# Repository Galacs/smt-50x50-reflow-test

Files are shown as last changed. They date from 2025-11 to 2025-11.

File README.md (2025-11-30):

# SMT 50x50 reflow test

ESP32-C6 50x50 board made to test smd reflow techniques with various components packages (QFN, HTSOP, WSON, USBC, SOT, SOIC, 0201)

## IC List

- ESP32-C6 (Main MCU)
- W25Q128JVSIQ (16MB program storage spi flash)
- 2x TMP117 (I2C temperature sensor)
- BMP581 (I2C/SPI pressure sensor)
- LMR36520 (wide Vin buck converter)
- LM317A (high Vin LDO)
- AP2112K (MCU LDO)
- 2450AT18A100E (2.45GHz Ceramic chip antenna)
- 01005 resistors

## Top preview



## Preview 3d render



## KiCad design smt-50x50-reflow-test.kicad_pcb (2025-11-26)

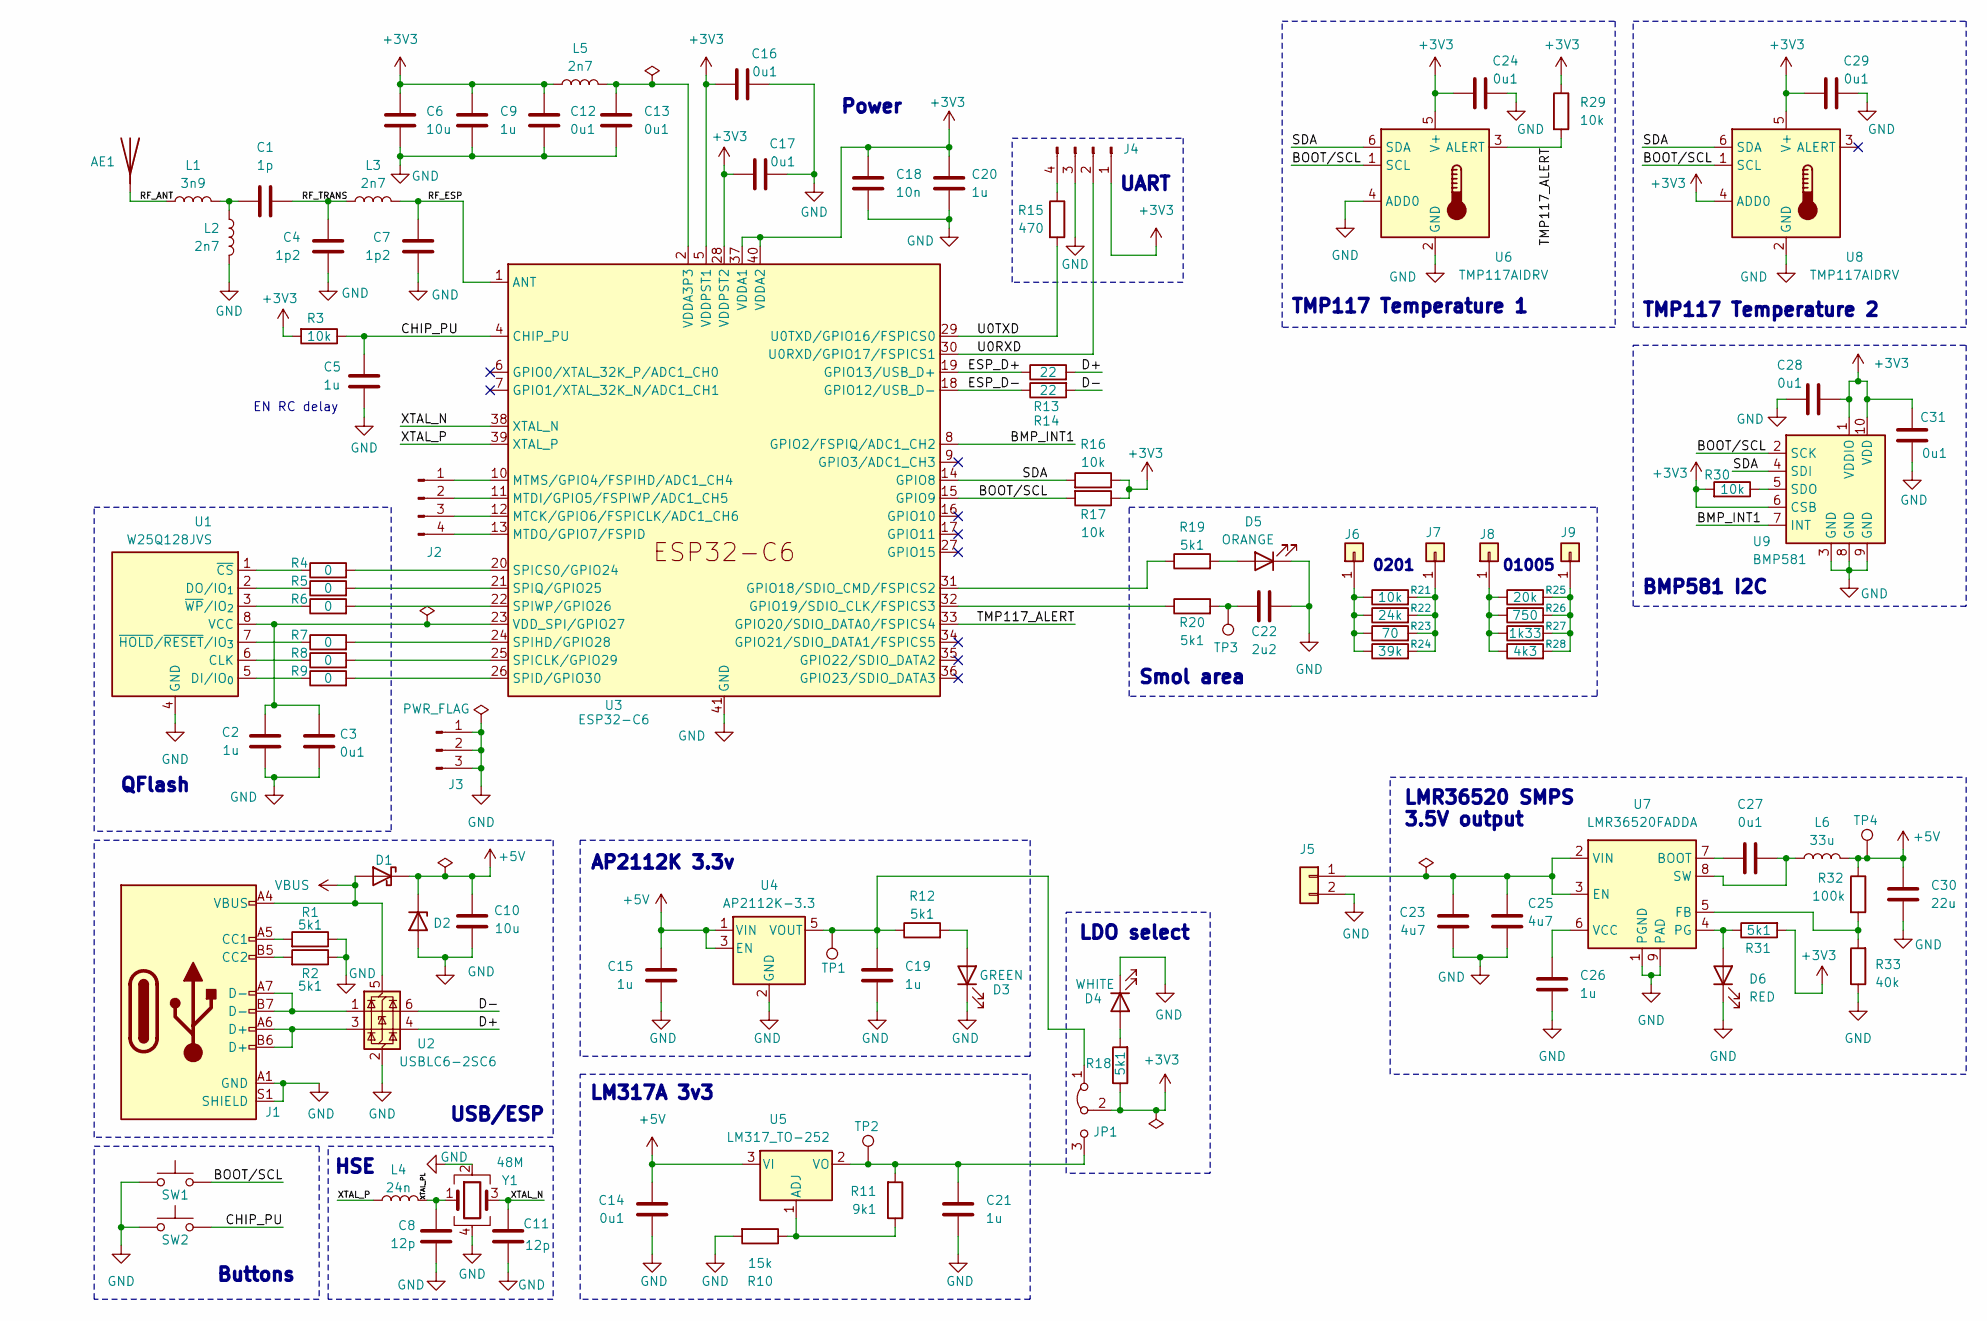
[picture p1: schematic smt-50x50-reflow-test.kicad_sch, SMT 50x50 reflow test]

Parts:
AE1: Antenna; Johanson_2450AT18x100; Manufacturer Part Number 2450AT18A100E; JLCPCB Part # C89334
C1: 1p; C_0402_1005Metric; Manufacturer Part Number 0402CG1R0C500NT; JLCPCB Part # C1550
C2, C5, C9, C20, C26: 1u; C_0402_1005Metric; Manufacturer Part Number CL05A105KA5NQNC; JLCPCB Part # C52923
C3, C12, C13, C16, C17, C24, C27, C28, C29, C31: 0u1; C_0402_1005Metric; Manufacturer Part Number CL05B104KB54PNC; JLCPCB Part # C307331
C4, C7: 1p2; C_0402_1005Metric; Manufacturer Part Number GJM1555C1H1R2WB01D; JLCPCB Part # C76899
C6, C10: 10u; C_0402_1005Metric; Manufacturer Part Number CL05A106MQ5NUNC; JLCPCB Part # C15525
C8, C11: 12p; C_0402_1005Metric; Manufacturer Part Number 0402CG120J500NT; JLCPCB Part # C1547
C14: 0u1; C_0603_1608Metric; Manufacturer Part Number CC0603KRX7R9BB104; JLCPCB Part # C14663
C15, C19, C21: 1u; C_0603_1608Metric; Manufacturer Part Number CL10A105KB8NNNC; JLCPCB Part # C15849
C18: 10n; C_0402_1005Metric; Manufacturer Part Number CL05B103KB5NNNC; JLCPCB Part # C15195
C22: 2u2; C_0201_0603Metric; Manufacturer Part Number GRM033R61A225KE47D; JLCPCB Part # C335106
C23, C25: 4u7; C_1206_3216Metric; Manufacturer Part Number 1206B475K500NT; JLCPCB Part # C29823
C30: 22u; C_0603_1608Metric; Manufacturer Part Number CL10A226MQ8NRNC; JLCPCB Part # C59461
D1: D_Schottky; D_SMA; Manufacturer Part Number SS54; JLCPCB Part # C22452
D2: H5VU10U; Diode_DFN1006; Manufacturer Part Number H5VU10U; JLCPCB Part # C22395519
D3: GREEN; LED_0805_2012Metric; Manufacturer Part Number KT-0805G; JLCPCB Part # C2297
D4: WHITE; LED_0603_1608Metric; Manufacturer Part Number KT-0603W; JLCPCB Part # C2290
D5: ORANGE; LED_0201_0603Metric; Manufacturer Part Number XL-0201UOC; JLCPCB Part # C5440629
D6: RED; LED_0603_1608Metric; Manufacturer Part Number KT-0603R; JLCPCB Part # C2286
J1: USB_C_Receptacle_USB2.0_14P; USB_C_Receptacle_HRO_TYPE-C-31-M-12; Manufacturer Part Number TYPE-C16PIN; JLCPCB Part # C393939
J2, J4: Conn_01x04_Pin; PinHeader_1x04_P2.54mm_Vertical
J3: Conn_01x03_Pin; PinHeader_1x03_P2.54mm_Vertical
J5: Conn_01x02; PinHeader_1x02_P2.54mm_Vertical
J6, J7, J8, J9: Conn_01x01; TestPoint_Pad_D1.0mm
JP1: Jumper_3_Bridged12; PinHeader_1x03_P2.54mm_Vertical
L1: 3n9; L_0402_1005Metric; Manufacturer Part Number LQG15HS3N9S02D; JLCPCB Part # C77109
L2, L3, L5: 2n7; L_0402_1005Metric; Manufacturer Part Number LQG15HS2N7S02D; JLCPCB Part # C77108
L4: 24n; L_0402_1005Metric; Manufacturer Part Number LQW15AN24NG00D; JLCPCB Part # C167472
L6: 33u; L_Chilisin_BMRx00060630; Manufacturer Part Number FXL0630-330-M; JLCPCB Part # C177245
R1, R2, R12, R18, R31: 5k1; R_0603_1608Metric; Manufacturer Part Number 0603WAF5101T5E; JLCPCB Part # C23186
R3, R29, R30: 10k; R_0603_1608Metric; Manufacturer Part Number 0603WAF1002T5E; JLCPCB Part # C25804
R4, R5, R6, R7, R8, R9: 0; R_0402_1005Metric; Manufacturer Part Number 0402WGF0000TCE; JLCPCB Part # C17168
R10: 15k; R_0603_1608Metric; Manufacturer Part Number 0603WAF1502T5E; JLCPCB Part # C22809
R11: 9k1; R_0603_1608Metric; Manufacturer Part Number 0603WAF9101T5E; JLCPCB Part # C23260
R13, R14: 22; R_0402_1005Metric; Manufacturer Part Number 0402WGF220JTCE; JLCPCB Part # C25092
R15: 470; R_0402_1005Metric; Manufacturer Part Number 0402WGF4700TCE; JLCPCB Part # C25117
R16, R17: 10k; R_0402_1005Metric; Manufacturer Part Number 0402WGF1002TCE; JLCPCB Part # C25744
R19, R20: 5k1; R_0201_0603Metric; Manufacturer Part Number 0201WMF5101TEE; JLCPCB Part # C270344
R21: 10k; R_0201_0603Metric; Manufacturer Part Number 0201WMF1002TEE C473048; JLCPCB Part # C473048
R22: 24k; R_0201_0603Metric; Manufacturer Part Number 0201WMF2402TEE; JLCPCB Part # C270353
R23: 70; R_0201_0603Metric; Manufacturer Part Number 0201WMF698JTEE; JLCPCB Part # C270692
R24: 39k; R_0201_0603Metric; Manufacturer Part Number 0201WMF3902TEE; JLCPCB Part # C473053
R25: 20k; R_01005_0402Metric; Manufacturer Part Number 0105WHJ0203TDE; JLCPCB Part # C560400
R26: 750; R_01005_0402Metric; Manufacturer Part Number RC0100FR-07750RL; JLCPCB Part # C850442
R27: 1k33; R_01005_0402Metric; Manufacturer Part Number MCR004QLPF1331; JLCPCB Part # C507485
R28: 4k3; R_01005_0402Metric; Manufacturer Part Number 0105WHF4301TDE; JLCPCB Part # C560366
R32: 100k; R_0603_1608Metric; Manufacturer Part Number 0603WAF1003T5E; JLCPCB Part # C25803
R33: 40k; R_0603_1608Metric; Manufacturer Part Number 0603WAF4022T5E; JLCPCB Part # C12447
SW1, SW2: SW_Push; SW_SPST_TS-1088-xR020; Manufacturer Part Number TS-1088-AR02016; JLCPCB Part # C720477
TP1, TP2, TP3, TP4: TestPoint; TestPoint_Pad_D2.0mm
U1: W25Q128JVS; SOIC-8_5.3x5.3mm_P1.27mm; Manufacturer Part Number W25Q128JVSIQ; JLCPCB Part # C97521
U2: USBLC6-2SC6; SOT-23-6; Manufacturer Part Number USBLC6-2SC6; JLCPCB Part # C7519
U3: ESP32-C6; QFN-40-1EP_5x5mm_P0.4mm_EP3.6x3.6mm_ThermalVias; Manufacturer Part Number ESP32-C6; JLCPCB Part # C5364646
U4: AP2112K-3.3; SOT-23-5; Manufacturer Part Number AP2112K-3.3TRG1; JLCPCB Part # C51118
U5: LM317_TO-252; TO-252-2; Manufacturer Part Number LM317AG-TN3-R; JLCPCB Part # C75510
U6, U8: TMP117AIDRV; WSON-6-1EP_2x2mm_P0.65mm_EP1x1.6mm; Manufacturer Part Number TMP117AIDRVR; JLCPCB Part # C699536
U7: LMR36520FADDA; Texas_HTSOP-8-1EP_3.9x4.9mm_P1.27mm_EP2.95x4.9mm_Mask2.4x3.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; Manufacturer Part Number LMR36520FADDAR; JLCPCB Part # C1858395
U9: BMP581; Bosch_LGA-10_2x2mm_P0.8mm_AntiClockwisePinNumbering; Manufacturer Part Number BMP581; JLCPCB Part # C5362283
Y1: 48M; Crystal_SMD_2016-4Pin_2.0x1.6mm; Manufacturer Part Number R940000096; JLCPCB Part # C7206306

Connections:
+3V3: C6.1, C9.1, C12.1, C16.1, C17.1, C18.1, C20.1, C24.1, C28.1, C29.1, C31.2, J4.1, JP1.2 (C), L5.1, R3.2, R16.1, R17.1, R18.1, R29.1, R30.2, R31.2, U3.5 (VDDPST1), U3.28 (VDDPST2), U3.37 (VDDA1), U3.40 (VDDA2), U6.5 (V+), U8.4 (ADD0), U8.5 (V+), U9.1 (VDDIO), U9.6 (CSB), U9.10 (VDD)
+5V: C10.1, C14.1, C15.1, C30.2, D1.1 (K), D2.1 (K), L6.2, R32.1, TP4.1, U4.1 (VIN), U4.3 (EN), U5.3 (VI)
/BMP_INT1: U3.8 (GPIO2/FSPIQ/ADC1_CH2), U9.7 (INT)
/BOOT/SCL: R17.2, SW1.2, U3.15 (GPIO9), U6.1 (SCL), U8.1 (SCL), U9.2 (SCK)
/CHIP_PU: C5.1, R3.1, SW2.2, U3.4 (CHIP_PU)
/D+: R13.2, U2.4 (I/O2)
/D-: R14.2, U2.6 (I/O1)
/ESP_D+: R13.1, U3.19 (GPIO13/USB_D+)
/ESP_D-: R14.1, U3.18 (GPIO12/USB_D-)
/RF_ANT: AE1.1 (A), L1.1
/RF_ESP: C7.1, L3.2, U3.1 (ANT)
/RF_TRANS: C1.1, C4.1, L3.1
/SDA: R16.2, U3.14 (GPIO8), U6.6 (SDA), U8.6 (SDA), U9.4 (SDI)
/TMP117_ALERT: R29.2, U3.33 (GPIO20/SDIO_DATA0/FSPICS4), U6.3 (ALERT)
/U0RXD: J4.2, U3.30 (U0RXD/GPIO17/FSPICS1)
/U0TXD: R15.2, U3.29 (U0TXD/GPIO16/FSPICS0)
/XTAL_N: C11.1, U3.38 (XTAL_N), Y1.3
/XTAL_P: L4.1, U3.39 (XTAL_P)
/XTAL_PL: C8.2, L4.2, Y1.1
GND: C2.2, C3.2, C4.2, C5.2, C6.2, C7.2, C8.1, C9.2, C10.2, C11.2, C12.2, C13.2, C14.2, C15.2, C16.2, C17.2, C18.2, C19.2, C20.2, C21.2, C22.2, C23.2, C24.2, C25.2, C26.2, C28.2, C29.2, C30.1, C31.1, D2.2 (A), D3.1 (K), D4.1 (K), D5.1 (K), D6.1 (K), J1.A1 (GND), J1.A12 (GND), J1.B1 (GND), J1.B12 (GND), J1.S1 (SHIELD), J3.1, J3.2, J3.3, J4.3, J5.2, L2.1, R1.1, R2.1, R10.2, R33.1, SW1.1, SW2.1, U1.4 (GND), U2.2 (GND), U3.41 (GND), U4.2 (GND), U6.2 (GND), U6.4 (ADD0), U7.1 (PGND), U7.9 (PAD), U8.2 (GND), U9.3 (GND), U9.8 (GND), U9.9 (GND), Y1.2, Y1.4
unnamed: C1.2, L1.2, L2.2
unnamed: C13.1, L5.2, U3.2 (VDDA3P3), U3.3 (VDDA3P3)
unnamed: C22.1, R20.2, TP3.1
unnamed: D3.2 (A), R12.2
unnamed: D4.2 (A), R18.2
unnamed: D5.2 (A), R19.2
unnamed: D6.2 (A), R31.1, U7.4 (PG)
unnamed: J1.A5 (CC1), R1.2
unnamed: J1.B5 (CC2), R2.2
unnamed: J1.A6 (D+), J1.B6 (D+), U2.3 (I/O2)
unnamed: J1.A7 (D-), J1.B7 (D-), U2.1 (I/O1)
unnamed: J2.1, U3.10 (MTMS/GPIO4/FSPIHD/ADC1_CH4)
unnamed: J2.2, U3.11 (MTDI/GPIO5/FSPIWP/ADC1_CH5)
unnamed: J2.3, U3.12 (MTCK/GPIO6/FSPICLK/ADC1_CH6)
unnamed: J2.4, U3.13 (MTDO/GPIO7/FSPID)
unnamed: J4.4, R15.1
unnamed: C23.1, C25.1, J5.1, U7.2 (VIN), U7.3 (EN)
unnamed: J6.1, R21.1, R22.1, R23.1, R24.1
unnamed: J7.1, R21.2, R22.2, R23.2, R24.2
unnamed: J8.1, R25.1, R26.1, R27.1, R28.1
unnamed: J9.1, R25.2, R26.2, R27.2, R28.2
unnamed: C19.1, JP1.1 (A), R12.1, TP1.1, U4.5 (VOUT)
unnamed: C21.1, JP1.3 (B), R11.2, TP2.1, U5.2 (VO)
unnamed: R8.1, U1.6 (CLK)
unnamed: R9.1, U1.5 (DI/IO_{0})
unnamed: R5.1, U1.2 (DO/IO_{1})
unnamed: C2.1, C3.1, U1.8 (VCC), U3.23 (VDD_SPI/GPIO27)
unnamed: R4.1, U1.1 (~CS)
unnamed: R7.1, U1.7 (~HOLD/~RESET/IO_{3})
unnamed: R6.1, U1.3 (~WP/IO_{2})
unnamed: R19.1, U3.31 (GPIO18/SDIO_CMD/FSPICS2)
unnamed: R20.1, U3.32 (GPIO19/SDIO_CLK/FSPICS3)
unnamed: R8.2, U3.25 (SPICLK/GPIO29)
unnamed: R4.2, U3.20 (SPICS0/GPIO24)
unnamed: R9.2, U3.26 (SPID/GPIO30)
unnamed: R7.2, U3.24 (SPIHD/GPIO28)
unnamed: R5.2, U3.21 (SPIQ/GPIO25)
unnamed: R6.2, U3.22 (SPIWP/GPIO26)
unnamed: R10.1, R11.1, U5.1 (ADJ)
unnamed: C27.2, U7.7 (BOOT)
unnamed: R32.2, R33.2, U7.5 (FB)
unnamed: C27.1, L6.1, U7.8 (SW)
unnamed: C26.1, U7.6 (VCC)
unnamed: R30.1, U9.5 (SDO)
VBUS: D1.2 (A), J1.A4 (VBUS), J1.A9 (VBUS), J1.B4 (VBUS), J1.B9 (VBUS), U2.5 (VBUS)

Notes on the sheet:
TMP117 Temperature 2
0201
UART
Smol area
HSE
LM317A 3v3
Buttons
AP2112K 3.3v
EN RC delay
BMP581 I2C
TMP117 Temperature 1
USB/ESP
Power
LMR36520 SMPS 3.5V output
01005
LDO select
QFlash

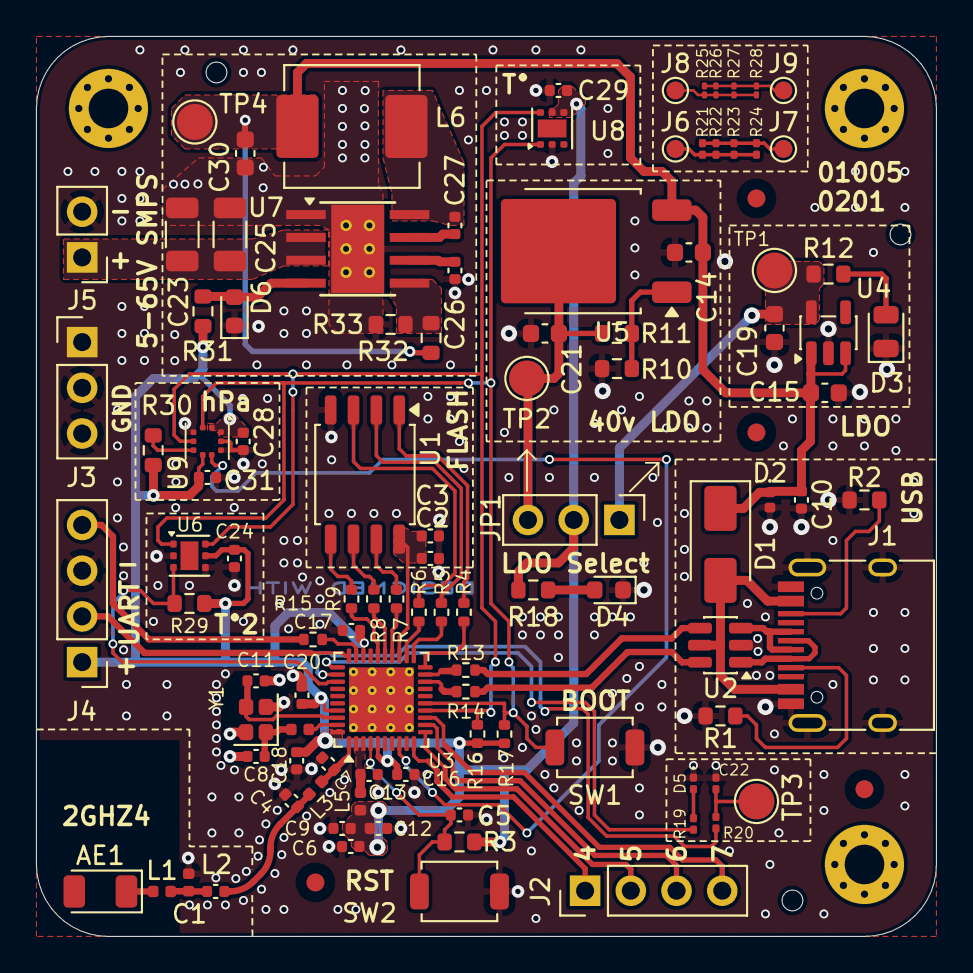
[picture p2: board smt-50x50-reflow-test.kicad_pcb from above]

Board: 4 copper layers, 50.0 x 50.0 mm, 103 parts (0 on the bottom side), 65 nets.

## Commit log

2025-11-15 schem: import esp32-c6, uart, usb-c, flash, crystal, buttons, tmp117, bmp581 from esp32c6-sensor-devboard
    [smt-50x50-reflow-test.kicad_sch]
2025-11-15 schem: add LM317A 3v3 ldo
    [smt-50x50-reflow-test.kicad_sch]
2025-11-15 schem: import AP2112K 3.3v ldo from esp32c6-sensor-devboard
    [smt-50x50-reflow-test.kicad_sch]
2025-11-15 schem: import ldo select from esp32s3-poc-devboard
    [smt-50x50-reflow-test.kicad_sch]
2025-11-15 schem: import LMR36520 3.5v smps from esp32c6-sensor-devboard
    [smt-50x50-reflow-test.kicad_sch]
2025-11-15 schem: add no connects
    [smt-50x50-reflow-test.kicad_sch]
2025-11-15 schem: add missing i2c net labels
    [smt-50x50-reflow-test.kicad_sch]
2025-11-15 schem: add missing footprints
    [smt-50x50-reflow-test.kicad_sch]
2025-11-15 schem: add ordering info to BOM
    [smt-50x50-reflow-test.kicad_sch]
2025-11-15 schem: add title
    [smt-50x50-reflow-test.kicad_sch]
2025-11-15 schem: add esd protection to usb vbus
    [smt-50x50-reflow-test.kicad_sch]
2025-11-15 pcb: import stackup
    [smt-50x50-reflow-test.kicad_pcb]
2025-11-15 pcb: fix missing 3d models
    [smt-50x50-reflow-test.kicad_pcb]
2025-11-15 pcb: add board outline
    [smt-50x50-reflow-test.kicad_pcb]
2025-11-15 pcb: add M2 mounting holes
    [smt-50x50-reflow-test.kicad_pcb]
2025-11-15 pcb: add M2 tooling holes
    [smt-50x50-reflow-test.kicad_pcb]
2025-11-15 pcb: add fiducials
    [smt-50x50-reflow-test.kicad_pcb]
2025-11-15 pcb: initial rough placement
    [smt-50x50-reflow-test.kicad_pcb]
2025-11-15 schem: run and fix ERC
    [smt-50x50-reflow-test.kicad_sch]
2025-11-15 pcb: placement refinement
    [smt-50x50-reflow-test.kicad_pcb]
2025-11-15 schem: add smol area
    [smt-50x50-reflow-test.kicad_sch]
2025-11-16 pcb: refine rf layout
    [smt-50x50-reflow-test.kicad_pcb]
2025-11-16 pcb: align headers on a 2.54mm grid
    [smt-50x50-reflow-test.kicad_pcb]
2025-11-16 pcb: add usb routing
    [smt-50x50-reflow-test.kicad_pcb]
2025-11-16 pcb: add internal gnd planes
    [smt-50x50-reflow-test.kicad_pcb]
2025-11-16 pcb: add stiching vias
    [smt-50x50-reflow-test.kicad_pcb]
2025-11-16 pcb: add rf routing
    [smt-50x50-reflow-test.kicad_pcb]
2025-11-16 pcb: add crystal routing
    [smt-50x50-reflow-test.kicad_pcb]
2025-11-16 pcb: add SPI FLASH routing
    [smt-50x50-reflow-test.kicad_pcb]
2025-11-16 pcb: add SMPS routing
    [smt-50x50-reflow-test.kicad_pcb]
2025-11-16 pcb: add 3v3 routing
    [smt-50x50-reflow-test.kicad_pcb]
2025-11-16 pcb: import smol area from schem
    [smt-50x50-reflow-test.kicad_pcb]
2025-11-16 pcb: add smol area layout
    [smt-50x50-reflow-test.kicad_pcb]
2025-11-16 pcb: add smol area routing
    [smt-50x50-reflow-test.kicad_pcb]
2025-11-16 pcb: add missing 3v3 routing
    [smt-50x50-reflow-test.kicad_pcb]
2025-11-16 pcb: add 5v routing
    [smt-50x50-reflow-test.kicad_pcb]
2025-11-16 pcb: add power section routing
    [smt-50x50-reflow-test.kicad_pcb, smt-50x50-reflow-test.kicad_sch]
2025-11-16 pcb: add i2c routing
    [smt-50x50-reflow-test.kicad_pcb]
2025-11-16 pcb: add spare gpio routing
    [smt-50x50-reflow-test.kicad_pcb]
2025-11-16 pcb: route CHIP_PU
    [smt-50x50-reflow-test.kicad_pcb]
2025-11-16 schem: remove one TMP117 alert line
    [smt-50x50-reflow-test.kicad_pcb, smt-50x50-reflow-test.kicad_sch]
2025-11-16 pcb: route TMP117 and BMP581 interrupts
    [smt-50x50-reflow-test.kicad_pcb, smt-50x50-reflow-test.kicad_sch]
2025-11-16 pcb(silkscreen): clean up reference designators
    [smt-50x50-reflow-test.kicad_pcb]
2025-11-16 pcb: add top and bottom gnd planes
    [smt-50x50-reflow-test.kicad_pcb]
2025-11-16 pcb: add stitching vias
    [smt-50x50-reflow-test.kicad_pcb]
2025-11-16 schem: run and fix DRC
    [smt-50x50-reflow-test.kicad_pcb]
2025-11-16 pcb: remove unused internal pads
    [smt-50x50-reflow-test.kicad_pcb]
2025-11-16 pcb(silkscreen): add user info
    [smt-50x50-reflow-test.kicad_pcb, smt-50x50-reflow-test.kicad_sch]
2025-11-16 pcb: finish silkscreen
    [smt-50x50-reflow-test.kicad_pcb]
2025-11-16 pcb: add title
    [smt-50x50-reflow-test.kicad_pcb]
2025-11-16 schem: add missing BOM info
    [smt-50x50-reflow-test.kicad_sch]
2025-11-16 pcb: add production files
    [smt-50x50-reflow-test.kicad_pcb]
2025-11-26 fix silkscreen and regenerate production files
    [smt-50x50-reflow-test.kicad_pcb]
2025-11-26 pcb: replace 何何 placeholder
    [smt-50x50-reflow-test.kicad_pcb]
